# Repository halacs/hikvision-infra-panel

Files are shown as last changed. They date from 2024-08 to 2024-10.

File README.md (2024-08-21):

# Infra panel designs Hikvision IP cameras

After a few months/years infra LEDs are gone and need to be replaced. Since there are no cheap replacement boards on the internet I made my own based on the original factory infra panel.

I used KiCad 8.0 and Ubuntu 22.04 LTS. I add the final gerber finels and some pictures as well to the repository.

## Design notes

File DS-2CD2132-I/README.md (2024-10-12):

# Infra panel for Hikvision DS-2CD2132-I

However, I designed this infra panel for my Hikvision DS-2CD2132-I cameras, it might fit for other Hikvision models too. I have no experience with other models yet. If you have please let me know, either via a pull request or in any other way. Thanks!

I noticed that I drawn my PCB maybe with too thin wirings so be careful with the lines near to the edges of the PCB. I cut one line off while I was placing the parts...

# Parts

- 1 pc socket: JOINT TECH A1250WV-4P
- 30 pcs 3mm 850 nm infrared LEDs
- 1 pcs BPV10NF 5mm 950nm photodiode (or L-93DP3BT 3mm phototransistor)

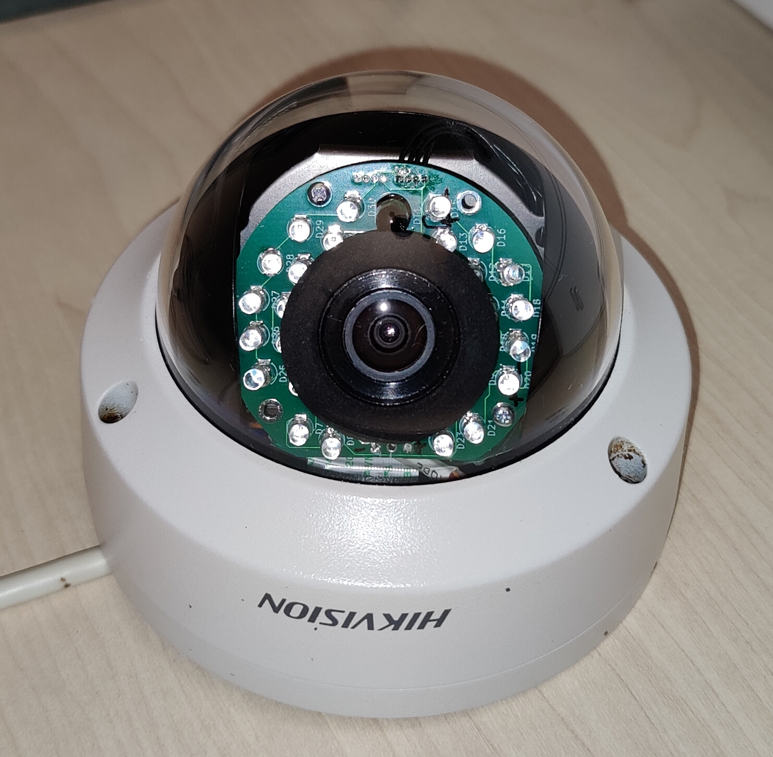
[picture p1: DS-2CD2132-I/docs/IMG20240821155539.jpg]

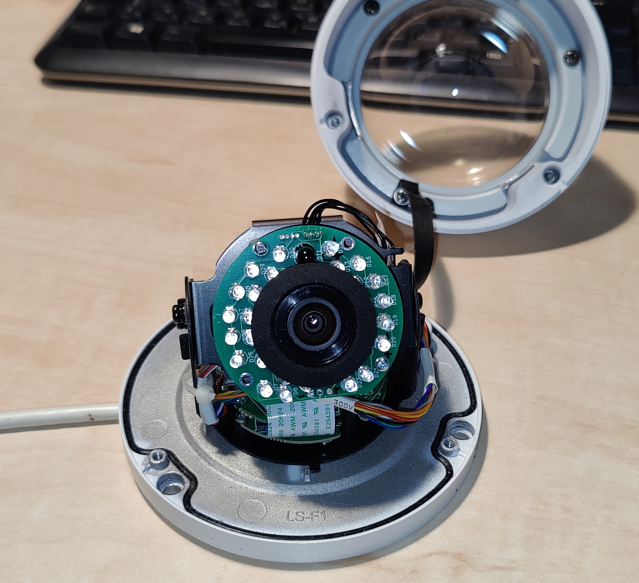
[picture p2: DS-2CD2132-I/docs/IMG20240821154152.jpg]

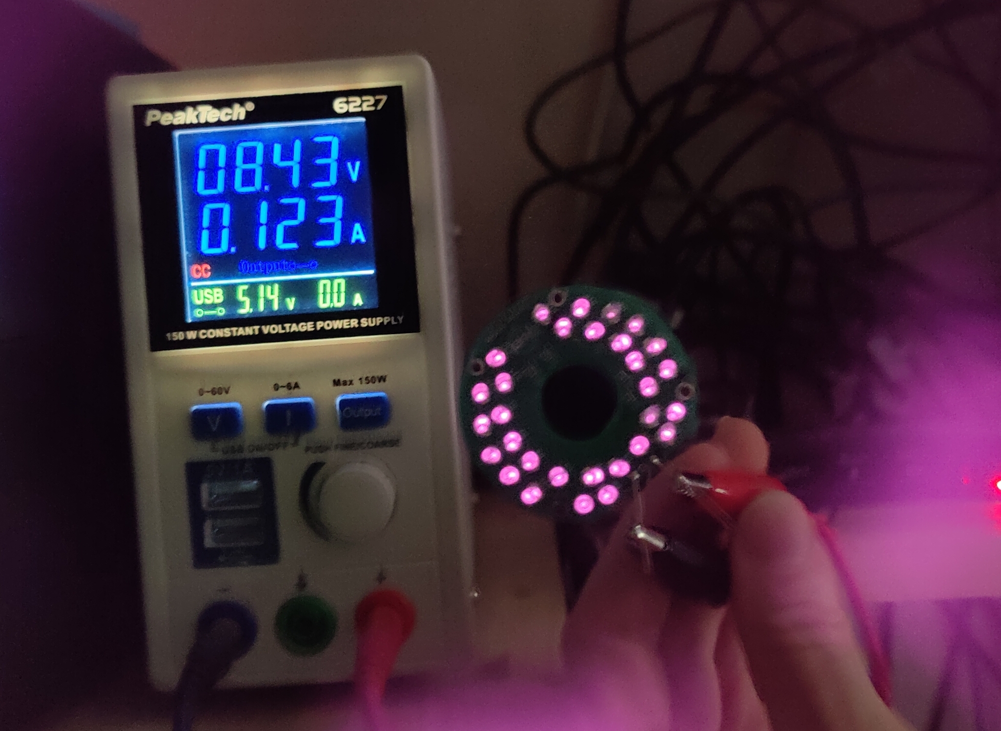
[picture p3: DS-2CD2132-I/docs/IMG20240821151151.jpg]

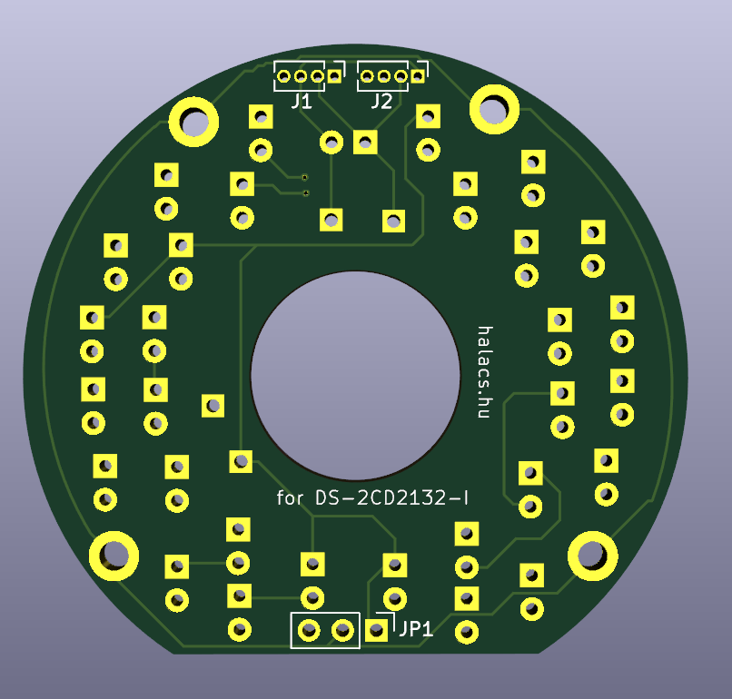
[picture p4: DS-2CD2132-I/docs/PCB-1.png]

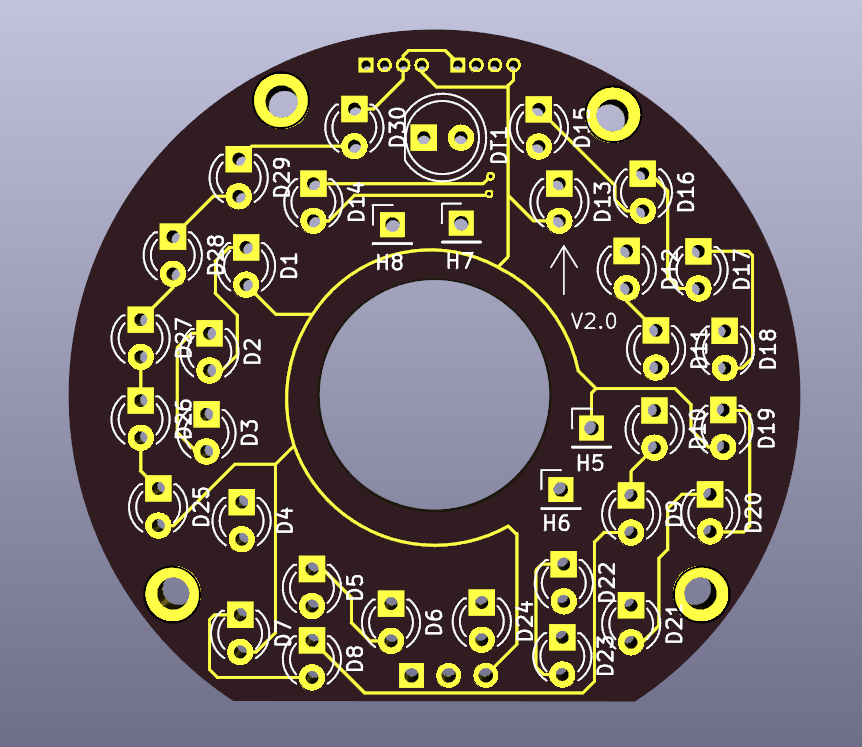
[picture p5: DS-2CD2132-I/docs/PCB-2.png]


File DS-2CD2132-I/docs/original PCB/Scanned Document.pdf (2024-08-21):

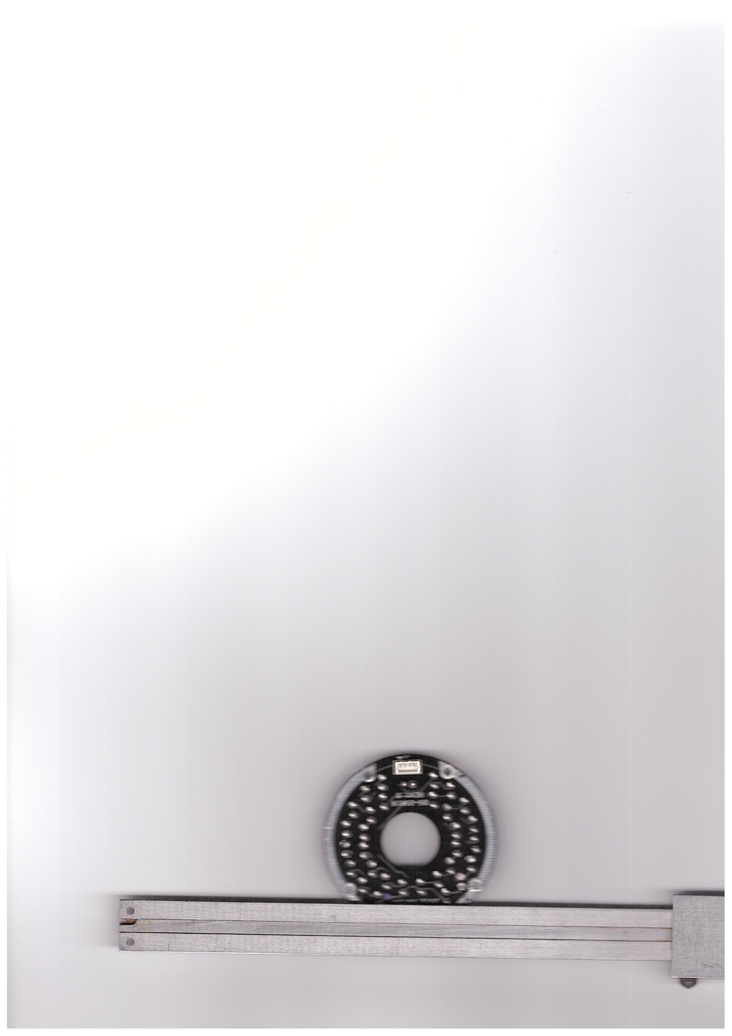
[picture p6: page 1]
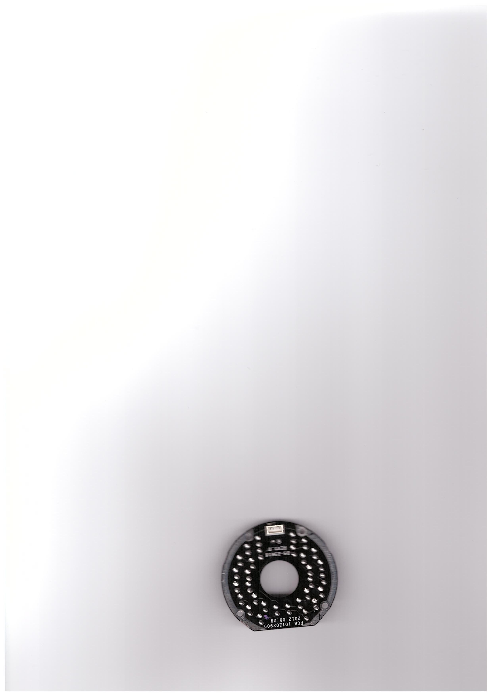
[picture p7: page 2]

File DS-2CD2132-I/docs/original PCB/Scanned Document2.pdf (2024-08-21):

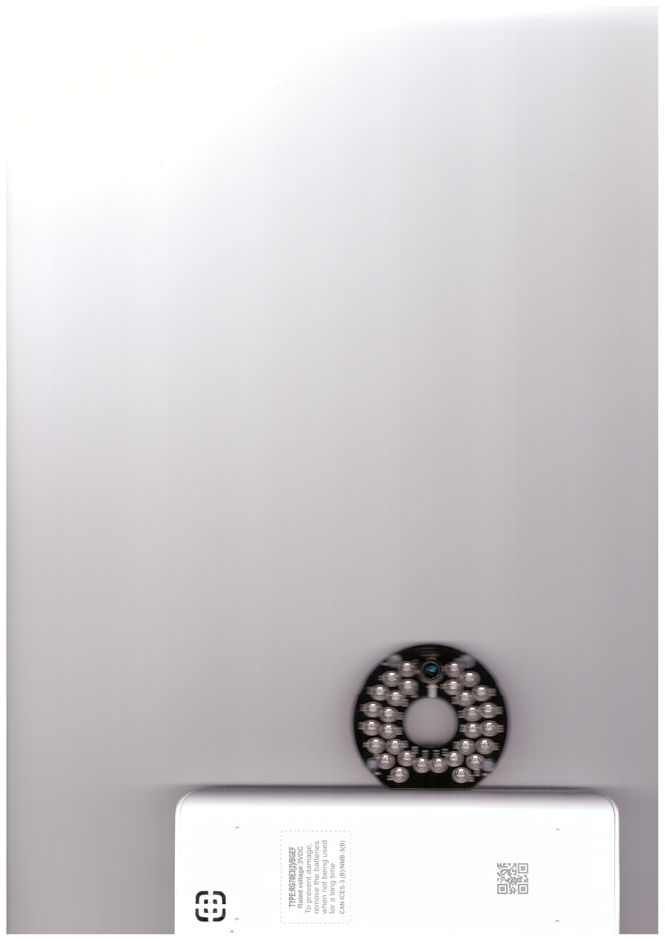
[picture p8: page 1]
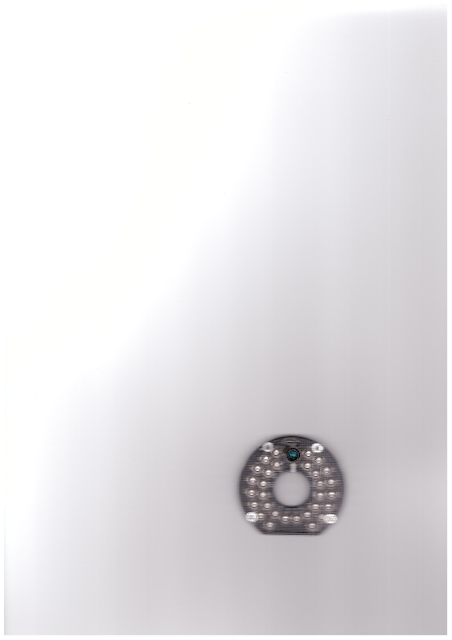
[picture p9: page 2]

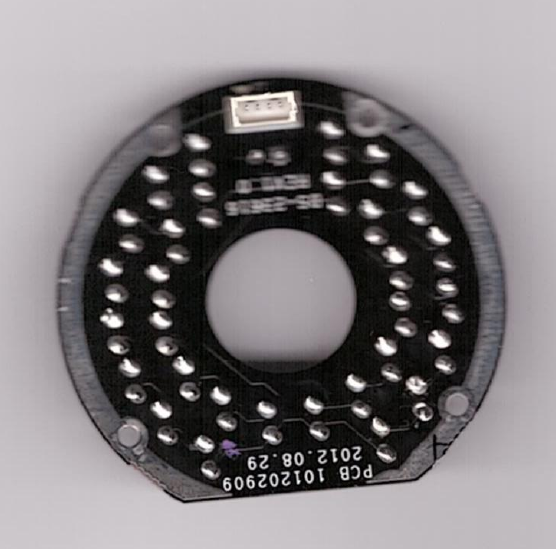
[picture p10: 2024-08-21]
DS-2CD2132-I/docs/original PCB/Screenshot from 2024-06-28 22-30-02.png

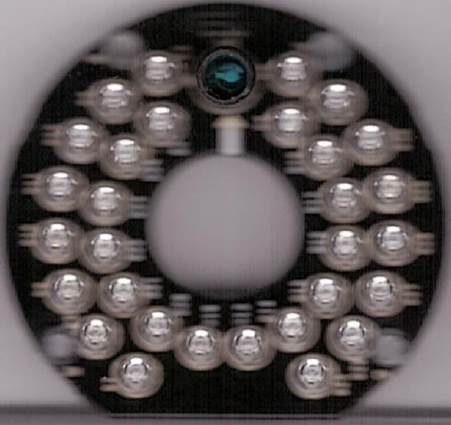
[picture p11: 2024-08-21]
DS-2CD2132-I/docs/original PCB/Screenshot from 2024-06-28 22-34-57.png

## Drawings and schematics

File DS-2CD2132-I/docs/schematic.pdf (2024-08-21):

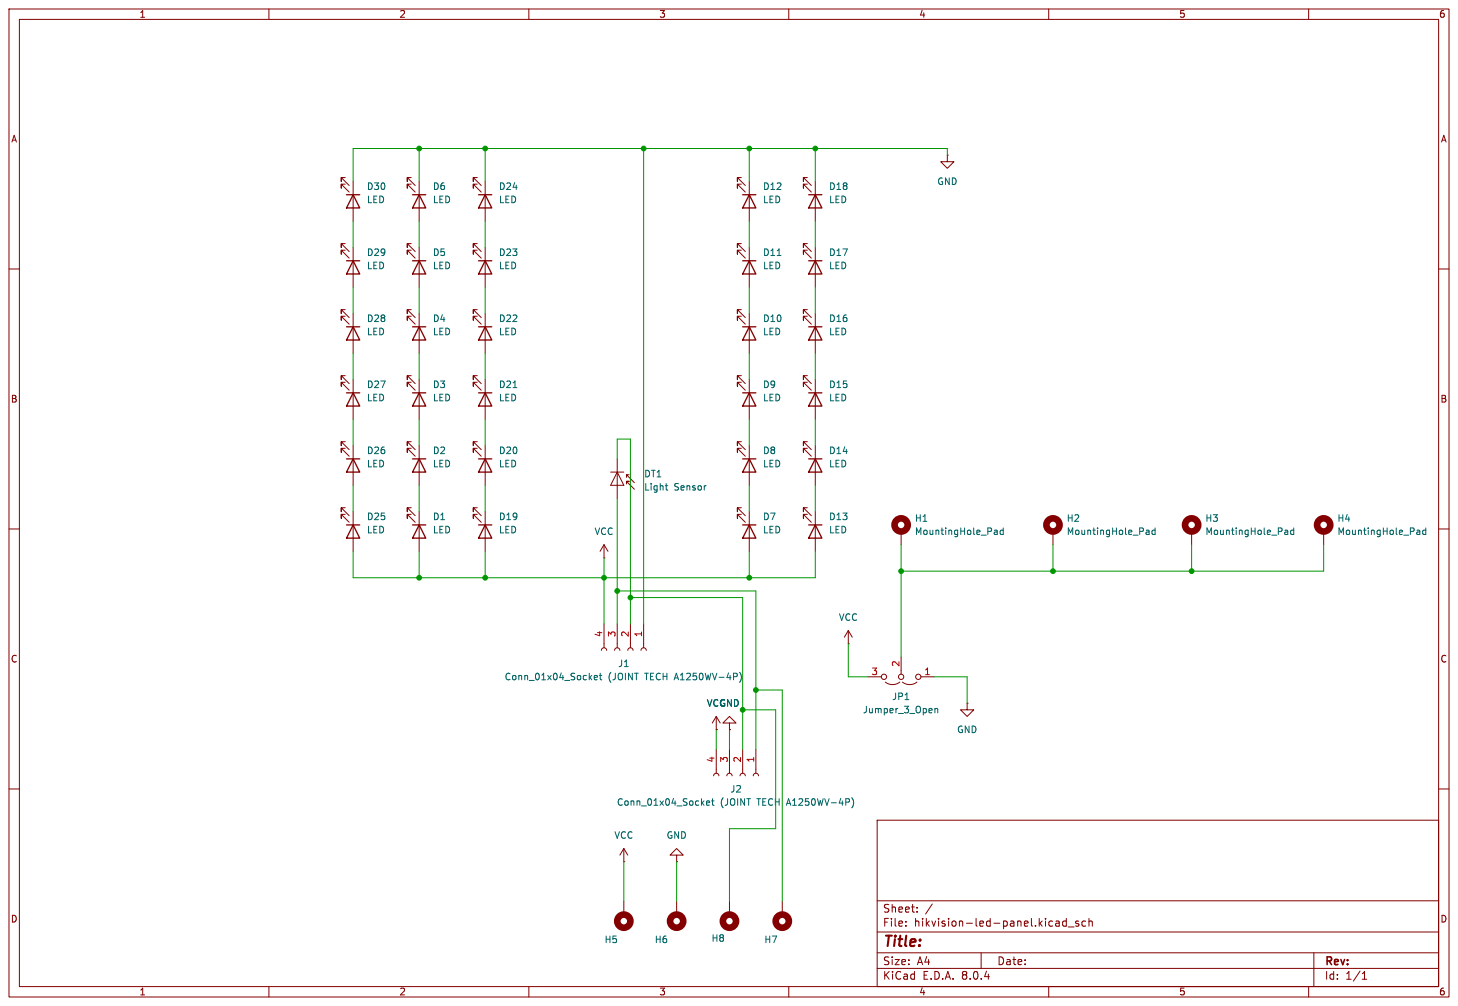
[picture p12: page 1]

Id: 1/1 Title: File: hikvision-led-panel.kicad_sch Sheet: / H6

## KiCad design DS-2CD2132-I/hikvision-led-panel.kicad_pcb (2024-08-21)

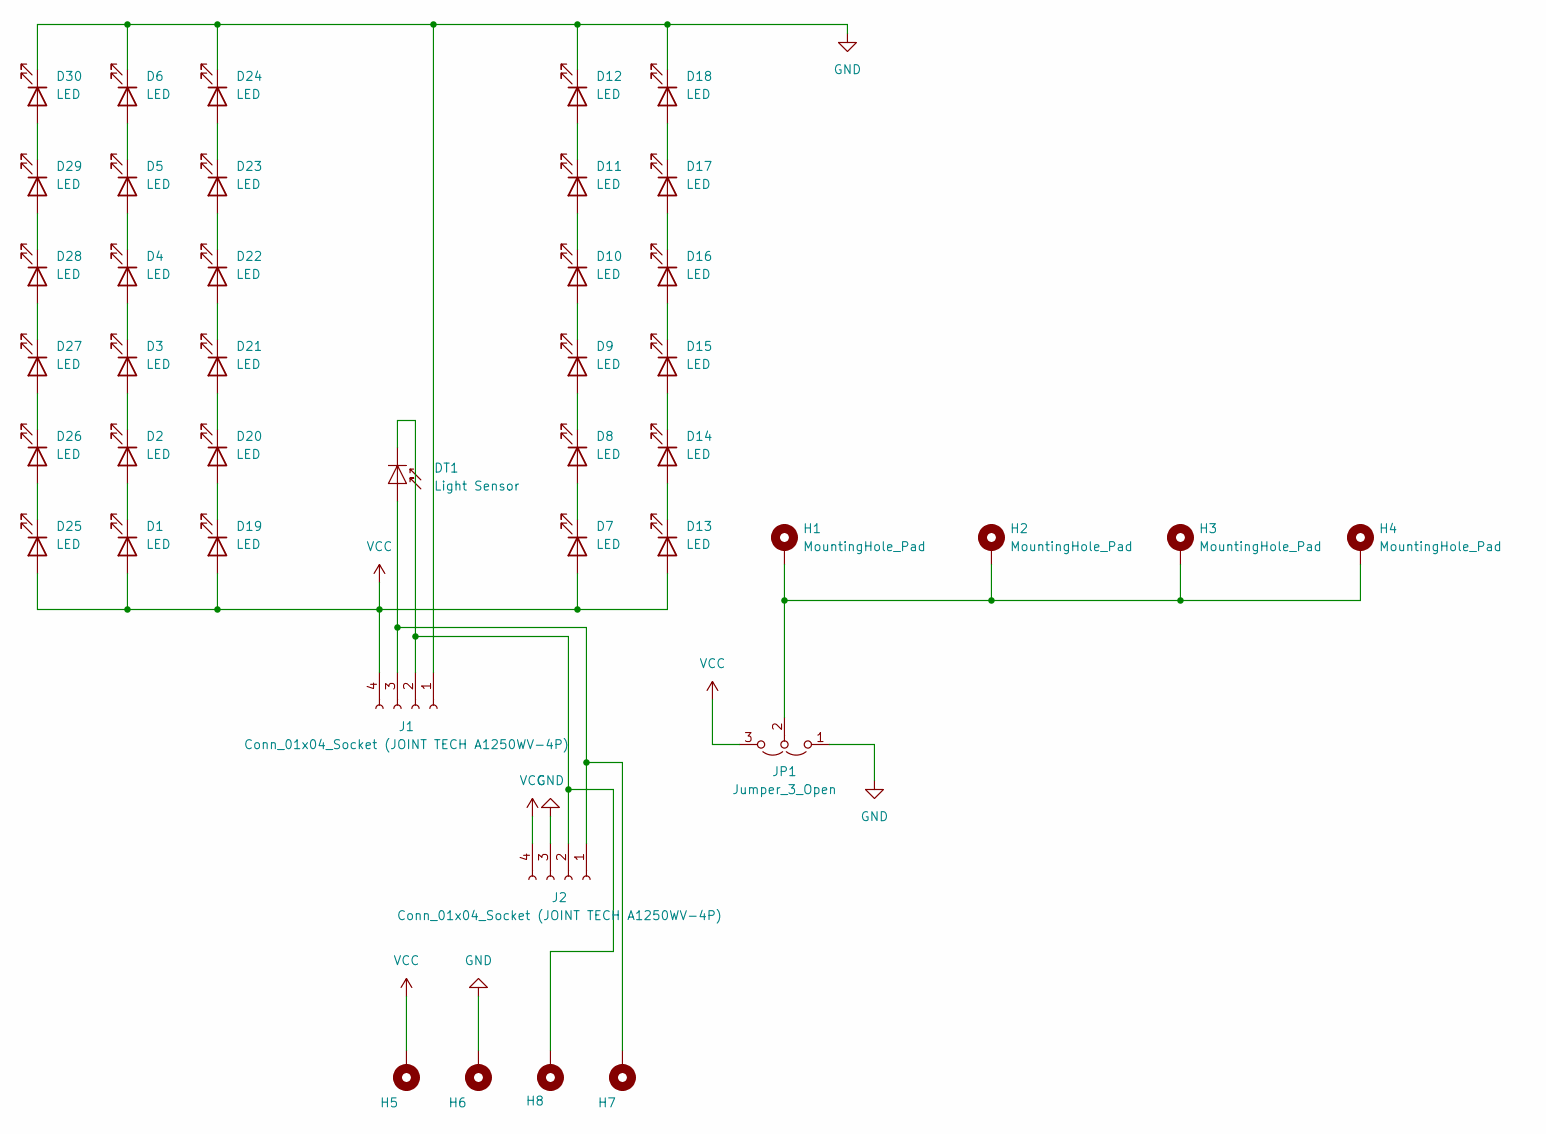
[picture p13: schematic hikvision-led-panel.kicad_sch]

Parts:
D1, D2, D3, D4, D5, D6, D7, D8, D9, D10, D11, D12, D13, D14, D15, D16, D17, D18, D19, D20, D21, D22, D23, D24, D25, D26, D27, D28, D29, D30: LED; LED_D3.0mm
DT1: Light Sensor; LED_D5.0mm
H1, H2, H3, H4: MountingHole_Pad; MountingHole_2.2mm_M2_DIN965_Pad
H5, H6, H7, H8: PinHeader_1x01_P2.54mm_Vertical
J1, J2: Conn_01x04_Socket (JOINT TECH A1250WV-4P); PinHeader_1x04_P1.27mm_Vertical
JP1: Jumper_3_Open; PinHeader_1x03_P2.54mm_Vertical

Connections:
GND: D6.1 (K), D12.1 (K), D18.1 (K), D24.1 (K), D30.1 (K), H6.1, J1.1, J2.3, JP1.1 (A)
unnamed: D1.1 (K), D2.2 (A)
unnamed: D2.1 (K), D3.2 (A)
unnamed: D3.1 (K), D4.2 (A)
unnamed: D4.1 (K), D5.2 (A)
unnamed: D5.1 (K), D6.2 (A)
unnamed: D7.1 (K), D8.2 (A)
unnamed: D8.1 (K), D9.2 (A)
unnamed: D9.1 (K), D10.2 (A)
unnamed: D10.1 (K), D11.2 (A)
unnamed: D11.1 (K), D12.2 (A)
unnamed: D13.1 (K), D14.2 (A)
unnamed: D14.1 (K), D15.2 (A)
unnamed: D15.1 (K), D16.2 (A)
unnamed: D16.1 (K), D17.2 (A)
unnamed: D17.1 (K), D18.2 (A)
unnamed: D19.1 (K), D20.2 (A)
unnamed: D20.1 (K), D21.2 (A)
unnamed: D21.1 (K), D22.2 (A)
unnamed: D22.1 (K), D23.2 (A)
unnamed: D23.1 (K), D24.2 (A)
unnamed: D25.1 (K), D26.2 (A)
unnamed: D26.1 (K), D27.2 (A)
unnamed: D27.1 (K), D28.2 (A)
unnamed: D28.1 (K), D29.2 (A)
unnamed: D29.1 (K), D30.2 (A)
unnamed: DT1.2 (A), H7.1, J1.3, J2.1
unnamed: DT1.1 (K), H8.1, J1.2, J2.2
unnamed: H1.1, H2.1, H3.1, H4.1, JP1.2 (C)
VCC: D1.2 (A), D7.2 (A), D13.2 (A), D19.2 (A), D25.2 (A), H5.1, J1.4, J2.4, JP1.3 (B)

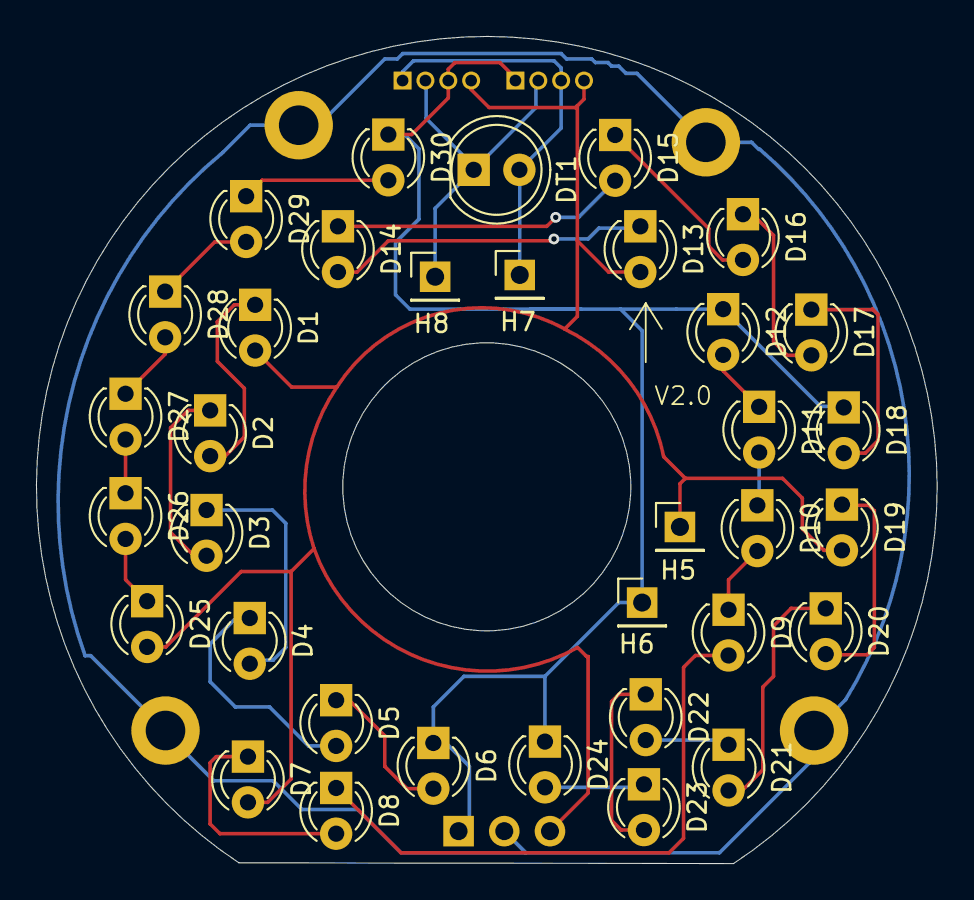
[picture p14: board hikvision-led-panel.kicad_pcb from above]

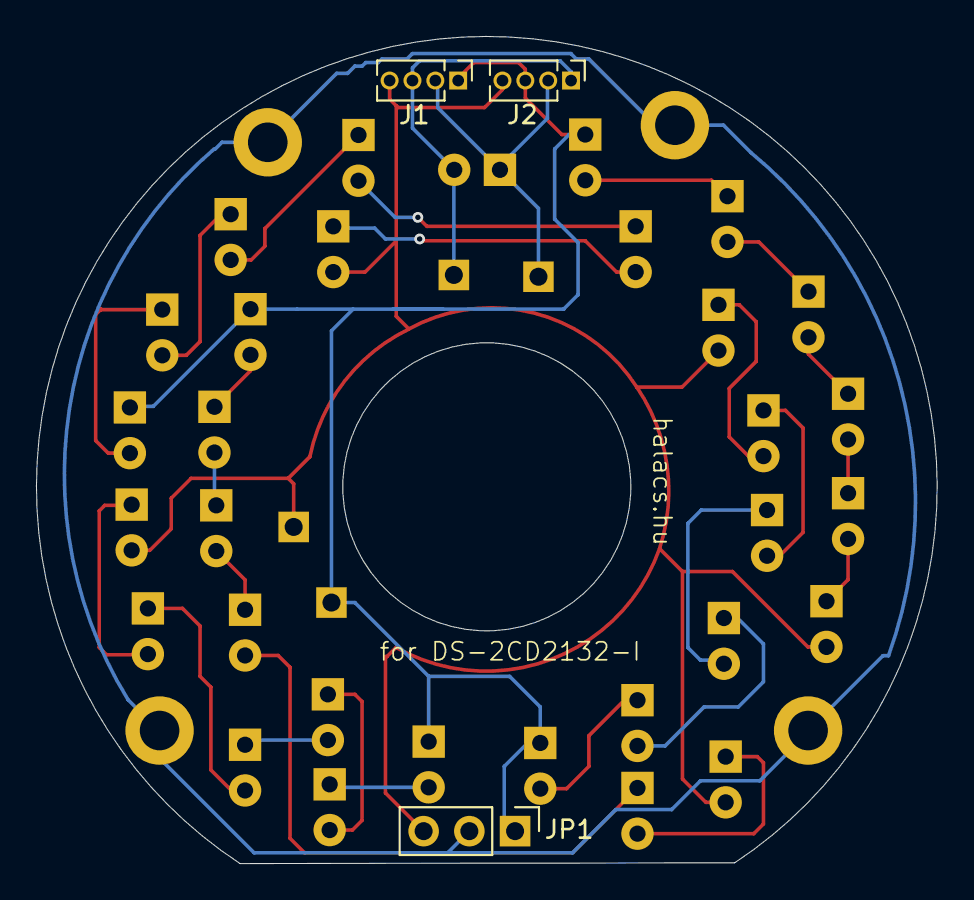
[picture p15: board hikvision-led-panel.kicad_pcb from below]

Board: 2 copper layers, 50.0 x 46.0 mm, 42 parts (3 on the bottom side), 30 nets.
